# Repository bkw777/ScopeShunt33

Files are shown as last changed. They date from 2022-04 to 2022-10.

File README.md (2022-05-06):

# ScopeShuntX

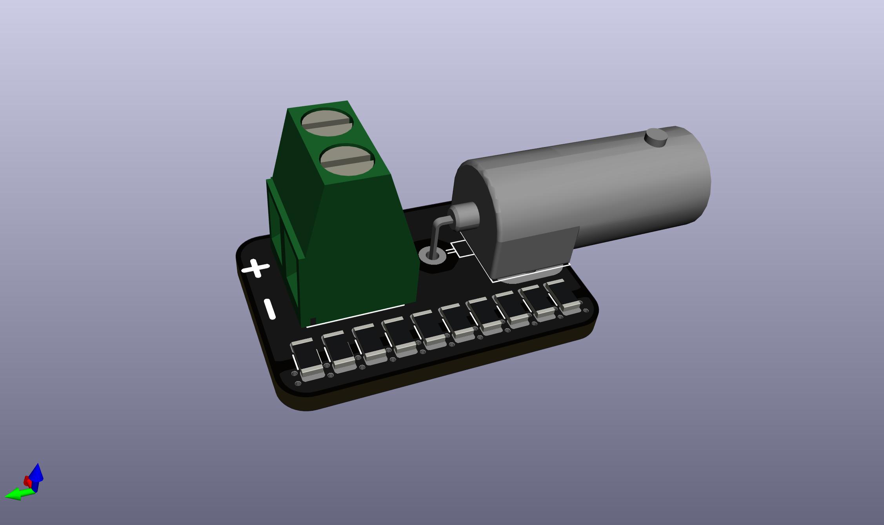
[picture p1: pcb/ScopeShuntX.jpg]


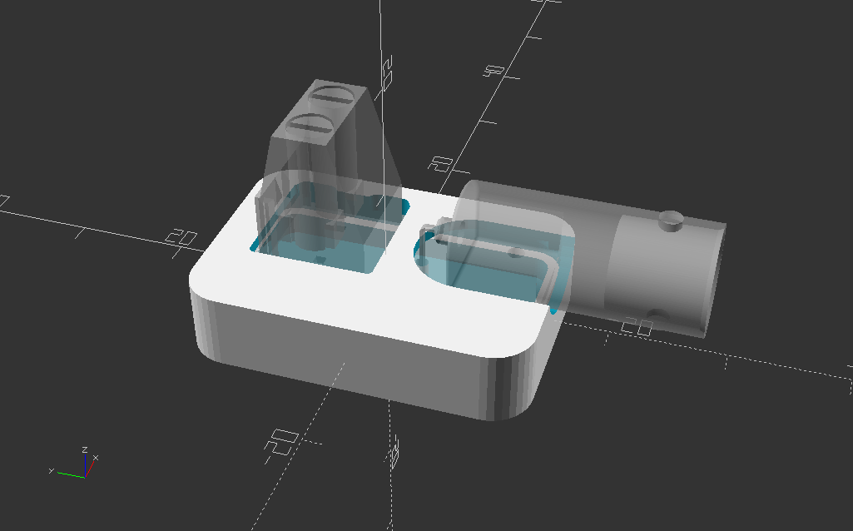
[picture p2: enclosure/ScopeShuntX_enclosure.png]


BOM https://www.digikey.com/short/3z3bj7z3

PCB https://www.pcbway.com/project/shareproject/ScopeShunt33_095d5357.html

PCB Gerbers & Enclusure STLs in [RELEASES](../../releases/)

# Resistor Values -> Current Ranges -> Scope Readings
The BOM above includes 10 mOhm resistors, which makes a shunt suitable for measuring 1A to 100A (Really only about 20A, see (2) below), which is mostly suitable for automotive work.

To measure other current ranges, substitute one of these other resistors instead.  
Remember in all cases to use:  
 * qty 10 resistors (a few spares is recommended also, but the PCB needs 10)  
 * 1206 size (normal, not "wide" orientation)  
 * 1% tolerance or less  
 * Recommend to use the highest power rating you can get, to make it less likely to destroy when accidentally connected to too-high current  

<!-- general search, all resistances https://www.digikey.com/short/wwhwwcjd -->

 | Individual<br>Resistors | Total<br>Resistance | Current<br>Range | Scope<br>Reading | Catasrophic<br>Failure |
 | --- | --- | --- | --- | --- |
 | [10 kOhm 1 W](https://www.digikey.com/short/cfbp8cz7) | 1 kOhm | 100 uA | 1 mV = 1 uA | 100mA 100V |
 | [1 kOhm 3/4 W](https://www.digikey.com/short/vp9hpb5z) | 100 Ohm | 1 mA | 1 mV = 10 uA | 270mA 27V (1) |
 | [100 Ohm 1 W](https://www.digikey.com/short/dbw91twt) | 10 Ohm | 10 mA | 1 mV = 100 uA | 1A 10V |
 | [10 Ohm 1 W](https://www.digikey.com/short/b54bzdjr) | 1 Ohm | 100 mA | 1 mV = 1 mA | 3A 3V |
 | [1 Ohm 3/4 W](https://www.digikey.com/short/f9hpctpn) | 100 mOhm | 1 A | 1 mV = 10 mA | 8.6A 860mV (1) |
 | [100 mOhm 1 W](https://www.digikey.com/short/brpqvpnv) | 10 mOhm | 10 A | 1 mV = 100 mA | 30A 300mV (2) |
 | [10 mOhm 1 W](https://www.digikey.com/short/mjnfq7dt) | 1 mOhm | 100 A | 1 mV = 1 A | 100A 100mV (2) |

 (1) Reflects the listed 3/4W resistors because 1W not available. Would be a little higher with 1W parts.

 (2) The practical current limit is much lower for a few reasons. In decreasing order:

 * This design uses size 1206 resistors, which aren't available in power ratings over 1W. 100A would be 100% of the resistors rated capacity, which they can't actually sustain for long. If the resitors were the only consideration, then the practical limit would be more like 75A for continuous use, 100A for brief periods  
 * The PCB uses zone fills rather than traces for all connections, so it's difficult to calculate the max current the PCB traces can carry. Here is a table based on 4mm wide traces x 2 traces per pin. The PCB has significantly more copper than this, and can probably handle significantly more than these values.  

 | CU Oz | Amps<br>+10°C | Amps<br>+45°C |
 | --- | --- | --- |
 | 1 | 6.4 | 13 |
 | 2 | 10  | 20 |
 | 3 | 13.5 | 27.5 |

TL,DR: If you're going to be routinely measuring over 10A, be sure to oder the PCB with 2oz copper or more.

 * The terminal block is only rated for 16A

# History / Credits
Inspired by https://github.com/voltlog/ScopeShunt

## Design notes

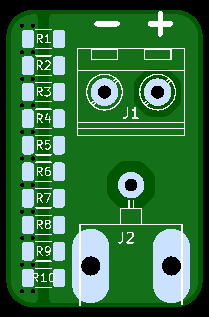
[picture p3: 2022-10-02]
pcb/top.png

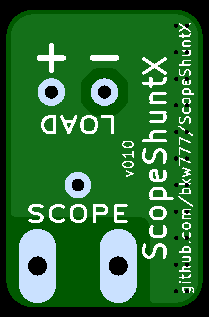
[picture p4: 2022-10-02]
pcb/bottom.png

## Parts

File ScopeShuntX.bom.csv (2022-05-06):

Index | Quantity | Part Number | Manufacturer Part Number | Description | Customer Reference | Available | Backorder | Unit Price | Extended Price USD
1 | 1 | 732-10955-ND | 691137710002 | TERM BLK 2POS SIDE ENTRY 5MM PCB |  | 1 | 0 | 0.39000 | 0.39
2 | 1 | J6536-ND | 415-0057-036 | CBL ASSY BNC PLUG-PLUG RG59 36" |  | 1 | 0 | 12.49000 | 12.49
3 | 1 | A32274-ND | 5414373-1 | CONN BNC JACK R/A 50 OHM PCB |  | 1 | 0 | 3.23000 | 3.23
4 | 10 | CFN1206-FX-R010ELFCT-ND | CFN1206-FX-R010ELF | RES 0.01 OHM 1% 1W 1206 |  | 10 | 0 | 0.43600 | 4.36

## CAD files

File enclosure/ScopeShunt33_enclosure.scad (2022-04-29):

// Enclosure for ScopeShunt33

// OUTPUT
/***********************************************************/
display_assembly();
//print_bottom();
//print_top();
//shell_bottom();
//shell_top();
/***********************************************************/

// To generate this STL model of the PCB:
// KiCad -> pcbnew -> File -> Export -> Step -> ScopeShunt33_pcb.step
// FreeCAD -> File -> open *.step -> select body -> File -> Export -> STL -> ScopeShunt33_pcb.stl
pcb_model_stl = "../pcb/ScopeShunt33_pcb.stl";

corner_radius = 2.5;
wall_thickness = 1;
pcb_thickness = 1.6;
pcb_length = 35;
pcb_width = 40;
pcb_x_offset = -5.5;  // pcb model stl center
pcb_y_offset = 0;     // "   "     "   "
top_components_thickness = 0.8; // resistors 0.65
bottom_components_thickness = 2;
top_perimeter_lip = 0.8;
bottom_perimeter_lip = 1;
fitment_clearance = 0.1;
snap_length = 6;
snap_thickness = wall_thickness;
snap_clearance = 0.3;
bnc_diameter = 9.7;
bnc_clearance = 1;

cr = corner_radius;
wt = wall_thickness;
fc = fitment_clearance;
pz = pcb_thickness;
px = pcb_length;
py = pcb_width;
tpl = top_perimeter_lip;
bpl = bottom_perimeter_lip;
tcz = top_components_thickness;
bcz = bottom_components_thickness;
sl = snap_length;
st = snap_thickness;
sc = snap_clearance;

o = 0.1; // cut/join overcut/overlap
$fn = 36;

tcoz = tcz+fc+wt+o; // top cut objects z

/***********************************************************/

module print_top () {
 translate([0,0,pz+tcz+fc+wt])
  rotate([0,180,0])
   shell_top();
}

module print_bottom () {
 translate([0,0,bcz+fc+wt])
  shell_bottom();
}

module display_assembly () {
 translate([pcb_x_offset,pcb_y_offset,0]) %pcb_model();
  /* translate([0,0,-10]) */ shell_bottom();
  shell_top();
}

module pcb_model () {
  import(pcb_model_stl);
}

module shell_top() {

 difference(){

  hull(){ // diff add
   or = cr + fc + wt;
   oh = wt + fc + tcz + pz + bcz + fc + wt;
   mirror_copy([1,0,0])
    translate([px/2-cr,0,0])  
     mirror_copy([0,1,0])
      translate([0,py/2-cr,oh/2-bcz-fc-wt])
       cylinder(h=oh,r=or,center=true);
   } // diff add

  group(){ // diff cut
   // pcb
   hull(){
    mirror_copy([1,0,0])
     translate([px/2-cr,0,0])  
      mirror_copy([0,1,0])
       translate([0,py/2-cr,-o/2-wt/2-fc/2-bcz/2+pz/2+fc/2])
        cylinder(h=o+wt+fc+bcz+pz+fc,r=cr+fc,center=true);
   }
   // upper cavity / lip
   hull(){
    ir = cr - tpl;
    mirror_copy([1,0,0])
     translate([px/2-tpl-ir,0,0])  
      mirror_copy([0,1,0])
       translate([0,py/2-tpl-ir,tcz/2+fc/2+pz])
        cylinder(h=tcz+fc,r=ir,center=true);
   }
   // holes
   bnc_hole();
   terminal_hole();
  } // diff cut
 } // difference

 // snaps male
 translate([0,0,st/2-bcz-fc-wt]) {
  mirror_copy([1,0,0])
   translate([-px/2-fc,0,0])
    rotate([90,0,0])
     cylinder(h=sl,d=st,center=true);
  mirror_copy([0,1,0])
   translate([0,-py/2-fc,0])
    rotate([0,90,0])
     cylinder(h=sl,d=st,center=true);
 } // snaps male

} // shell_top()

module shell_bottom() {
 difference() {
  // add
  // outer hull
  oh = wt + fc + bcz; // height
  hull() {
   mirror_copy([1,0,0])
    translate([px/2-cr,0,0])
     mirror_copy([0,1,0])
      translate([0,py/2-cr,oh/2-bcz-fc-wt])
       cylinder(h=oh,r=cr,center=true);
  }

  // cut
  group () {
   // main cavity
   hull () {
    ir = cr - bpl;
    ix = px - bpl*2;
    iy = py - bpl*2;
    mirror_copy([1,0,0])
     translate([ix/2-ir,0,0])
      mirror_copy([0,1,0])
       translate([0,iy/2-ir,oh/2-bcz-fc])
        cylinder(h=oh,r=ir,center=true);
   }
   
   // snaps female
   sx = 1+sl+1;
   sy = o+st/2+sc;
   sz = st+sc+o;
   translate([0,0,sz/2-bcz-fc-wt-o]){
    mirror_copy([0,1,0])
     translate([0,-py/2-fc/2-o+sy/2,0])
      cube([sx,sy,sz],center=true);
    mirror_copy([1,0,0])
     translate([-px/2-fc/2-o+sy/2,0,0])
      cube([sy,sx,sz],center=true);
    }
  }

 } // difference
} // shell_bottom()

module terminal_hole() {
 translate([11.5,14,tcoz/2+pz])
  hull()
   mirror_copy([0,1,0])
    translate([0,5,0])
     mirror_copy([1,0,0]) 
      translate([5,0,0])
       cylinder(h=tcoz,r=0.4,center=true);
  // clearance for the dovetails
  translate([16.3,14.5,tcoz/2+pz])
   mirror_copy([0,1,0])
    translate([0,3.55,0])
     cylinder(h=tcoz,r=1.2,center=true);
}

module bnc_hole () {
 vw = bnc_diameter + bnc_clearance; // vertical width
 hw = fc + bnc_diameter + fc; // horizontal width
 bxo = 11.5; // bnc x offset
 cr = 0.4; //corner radius
 // hole in wall
 translate([bxo,-(o+wt+fc+tpl+o)/2-py/2+tpl+o,5.45])
  rotate([90,0,0])
   cylinder(h=o+wt+fc+tpl+o,d=vw,center=true);
 // hole in top
 translate([bxo,-13,tcoz/2+pz])
  hull(){
   cylinder(h=tcoz,d=hw,center=true);
   translate([0,cr-7.1,0])
    hull()
     mirror_copy([1,0,0])
      translate([hw/2-cr,0,0])
       cylinder(h=tcoz,r=cr,center=true);
  }
}

module mirror_copy(v) {
 children();
 mirror(v) children();
}

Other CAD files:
enclosure/ScopeShuntX_enclosure.scad

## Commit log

2022-04-23 screw terminal footprint
    [ScopeShunt33.bom.csv, ScopeShunt33.kicad_pcb, ScopeShunt33.sch]
2022-04-23 bnc connector
    [ScopeShunt33.bom.csv, ScopeShunt33.kicad_pcb]
2022-04-23 smaller pcb
    [ScopeShunt33.kicad_pcb]
2022-04-24 connector arrangement
    [ScopeShunt33.kicad_pcb]
2022-04-26 add enclosure
    [ScopeShunt33_enclosure.scad]
2022-04-26 enclosure printability & part fitment
    [ScopeShunt33.kicad_pcb, ScopeShunt33_enclosure.scad]
2022-04-26 via sizes
    [ScopeShunt33.kicad_pcb]
2022-04-28 enclosure fit and snaps
    [ScopeShunt33_enclosure.scad]
2022-04-28 enclosure snaps
    [ScopeShunt33_enclosure.scad]
2022-04-29 snap fit
    [ScopeShunt33_enclosure.scad]
2022-05-06 change to 10x1206 resistors
    [ScopeShunt33.bom.csv, ScopeShunt33.kicad_pcb, ScopeShunt33.sch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]
2022-10-02 kicad 6
    [ScopeShuntX.kicad_pcb, ScopeShuntX.kicad_sch, ScopeShuntX.sch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]
